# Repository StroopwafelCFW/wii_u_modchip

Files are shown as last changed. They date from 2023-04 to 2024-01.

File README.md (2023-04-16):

# wii_u_modchip

A (WIP) Wii U modchip based on de_Fuse, a flaw in the Wii U's OTP eFuse readout state machine.

## How does it work?
A full writeup is available [here](https://douevenknow.us/post/714056575412764672/defuse-the-one-true-pwn). However, the short version is as follows:

In order to accommodate eFuse-based JTAG lockout (and due to other considerations), eFuse bits must be buffered into a register file immediately following NRST, before the internal reset can be released. The eFuse sense state machine latches at a rate of 4 bits per cycle, directly off the 27MHz XTALCLK. Every other rising edge, a byte is written into the register file, starting from the least significant byte of the current u32.

An internal counter is used to keep track of the remaining bytes to be read into the register file. While the eFuse register file is reset to zero with NRST, the internal counter is not: By asserting NRST after N bytes have been read, only 0x400-N bytes will be read on the subsequent boot.

By asserting NRST just before the final byte has been read (1830 cycles), all eFuses will read entirely zero, including the JTAG lockout fuse. This allows trivial, unsigned and unencrypted boot1 execution, with no SEEPROM anti-rollback.

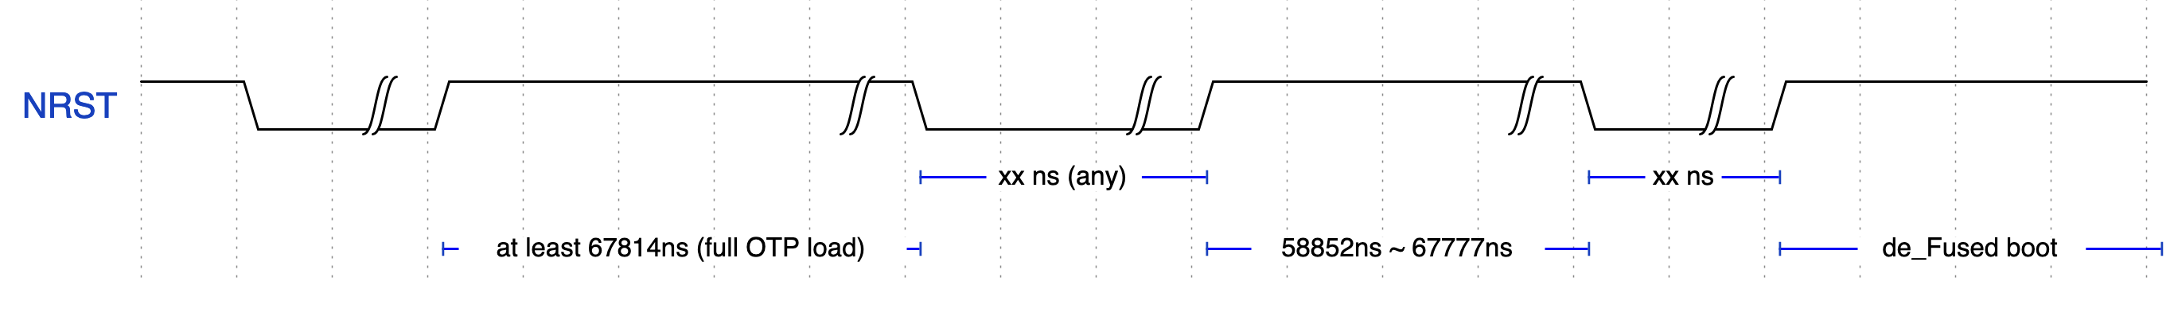
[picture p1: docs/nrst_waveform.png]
NRST waveform


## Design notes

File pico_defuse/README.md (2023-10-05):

# pico de_Fuse

Based on [PicoBoot](https://github.com/webhdx/PicoBoot)

## Wiring

| Pico Pin Name  | Wii U Testpoint | Description |
| --- | --- | --- |
| GP2 | TP50 | DEBUG0 |
| GP3 | TP51 | DEBUG1 |
| GP4 | TP52 | DEBUG2 |
| GP5 | TP53 | DEBUG3 |
| | | |
| GP6 | TP55 | DEBUG4 |
| GP7 | TP54 | DEBUG5 |
| GP8 | TP48 | DEBUG6 |
| GP9 | TP49 | DEBUG7 |
| | | |
| GP10 | TP176 | EXI0 MISO |
| GP11 | TP176 | EXI0 MISO |
| GP12 | TP176 | EXI0 MISO |
| GP13 | TP176 | EXI0 MISO |
| | | |
| GP14 | TP101 | EXI0 CLK |
| GP15 | TP144 (alternatively: R677) | NRST |
| | | |
| GP18 | TP48 | DEBUG6 |
| GP19 | TP48 | DEBUG6 |
| GP20 | TP48 | DEBUG6 |
| GP21 | TP48 | DEBUG6 |
| | | |
| GND |  GND, and/or TP164 | GND |
| 3V3(OUT) |  TP122 | Always-On 3.3v |

wiring diagram
(Thanks to JadeStrike for the wiring diagram)

For wiring to the Pico, I highly suggest using [~38AWG enameled magnet wire](https://www.amazon.com/BNTECHGO-AWG-Magnet-Wire-Transformers/dp/B0823C7C2H) (**not** solid core or stranded). Some of the test points are close to the GPU voltage rails (which are high amperage); A poor solder joint breaking off and touching something else can be catastrophic.

The best location to mount the Pico is still an open question. For my main Wii U, I'm currently planning on placing kapton tape over the Nintendo logo on the top side of the PCB, wrapping my Pico in kapton tape, and then adhering the Pico to the kapton tape with double-sided foam. Wires can be safely routed from the bottom of the PCB to the top through the WiFi antenna divots. I'm also planning on using a [microUSB breakout board](https://www.amazon.com/Adafruit-Micro-B-Breakout-Board-ADA1833/dp/B00KLDPZVU) (wired to the Pico Testpoints) above the HDMI port for serial output.

Apparently some people have managed to [shove entire SSDs](https://gbatemp.net/threads/wii-u-internal-ssd-with-activity-led.606315/) on the underside of the board using electrical tape, so space clearly isn't that big of an issue. But the bigger issue is that the Pico microUSB is currently the only way to perform backups/restores/diagnostics (and the firmware hasn't quite finalized yet), so the USB cable from the Pico has to go ~somewhere out the front of the console or the back.

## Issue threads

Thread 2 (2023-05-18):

Better way of flashing the `pico_defuse` firmware

Supermath101, 2023-05-18:
In the `pico_defuse` README, it says:
> [... But the bigger issue is that the Pico microUSB is currently the only way to perform backups/restores/diagnostics (and the firmware hasn't quite finalized yet), so the USB cable from the Pico has to go ~somewhere out the front of the console or the back.](https://github.com/shinyquagsire23/wii_u_modchip/blob/main/pico_defuse/README.md?plain=1#L39)

I have a suggestion: You can connect a pair of wires (and ground) to the debug pins to load firmware without needing a direct USB connection. You'll want to use the Raspberry Pi Debug Probe (or any standard SWD debugger).

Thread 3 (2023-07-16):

The minute menu does not start v0.7.

Viperbite, 2023-07-16:
1. Recorded boot1 - v0.7 on the card.
2. Copied FW.bin and the WiiU folder.
3. Inserted the card into the console and pressed the power button.
The console turned on, blinked a purple diode and after 20-30 seconds began to blink orange, there is no picture on the screen all this time.

Decision.
1. Write boot1 v0.5.1 to the card.

Question:
1. Is it possible to launch RedNAND at the moment??

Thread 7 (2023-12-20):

Can be done with a esp32 instead a pico?

EnigmaHall, 2023-12-20:
If yes, how?

shinyquagsire23, 2023-12-20:
In theory sure, in practice the Pico's PIO makes everything 10x easier, and making that work on other microcontrollers is left as an exercise for the reader

EnigmaHall, 2023-12-23:
the esp32 is faster and maybe could use the wifi. But my reason is because i dont have a pico. But I understand, remake the work for esp32 take time and effort. Well I will keep my fingers crossed.

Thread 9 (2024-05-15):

[Troubleshooting] Failure to dump OTP.bin with v1.0

VariablePwn, 2024-05-15:
I've tried all day to get OTP.bin to dump with PRSHhax, but unfortunately it would not work at all.
After reading through the GBATemp articles, it seems someone dried using an older version and it worked for them.
I flash v0.8 onto my pico, and overwrote the files on the SD card, and on my second attempt successfully dumped OTP.bin (at least according to the console).

jan-hofmeier, 2024-09-30:
This is fixed in the v1.1 release

Closed 2024-09-30.

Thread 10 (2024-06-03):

You can add a recommended safe GPU overclock range, as the nx venom team?

Armandprogame, 2024-06-03:
Hello Shine, you feel you could add some recommended clock for the wii u gpu so that those who want can overclock it without the risk of breaking it (I know it breaks before but at least I want a overclock safe)

shinyquagsire23, 2024-06-03:
I think something like 800MHz was the theoretical maximum? ie, it crashed the console. But aside from that, it's basically whatever the cooler can safely handle. I honestly don't recommend an overclock *at all* unless you're also doing like, a custom cooler or live in a cold apartment or something.

Armandprogame, 2024-06-03:
Ok thank you then 550mhz and the default while 800mhz is the max but it is only recommended if I have thermal paste or thermal pads aftermarket. Right?

Armandprogame, 2024-06-03:
However, the ihs of the wii u is made of aluminium or and nickel-plated copper? (I know that the heat sink and aluminum so rip contactonaut)

shinyquagsire23, 2024-06-06:
Approximately 750Mhz ± 100MHz, depending on silicon lottery, whether your Wii U is B1X (die shrink), thermal paste and heatsink, probably other factors.

Armandprogame, 2024-06-24:
Shinyquagsire23 I found the safe clock range for the wii u and it's between 550mhz and 600mhz (because it's the maximum frequency of the original wii u video card or amd radeon E6760) and nothing I wanted to know if you could do the test of overclocking the wii u no longer at 680mhz but at 600mhz and see if it overheats anyway. if not then I see and invent a hypothetical overclock that Nintendo would do its own (which is usually and quite undersized)

Armandprogame, 2024-06-24:
I have seen precisely what the native clock of the Wii U amounts to in terms of percentage, or 550mhz and equals a performance efficiency of 91.5/91.6% obviously not and at most of its possibilities that it is 600mhz also considering the fact that the CPU is already at 100% of the maximum working clock already preset by Nintendo instead of which in the video card has been deliberately downclocked by 50mhz, so try this new frequency and let me know if it does not heat more. @
![Screenshot_20240624_134530_Chrome] (https://github.com/shinyquagsire23/wii_u_modchip/assets/115667084/722abba8-540d-4d2a-97df-0657d756046e)

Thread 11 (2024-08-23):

[Question] Wiring additional usb port

dazzaXx, 2024-08-23:
Hello!

I'm planning on adding an extra usb port to the pico via the test pads on it as recommended. Would I need to wire power from the new usb port to the pico? Or is it just the data lines and ground.

Thank You!

dazzaXx, 2024-08-25:
It is just the data lines and ground, also don't wire the usb port to one of the Wii U's. Doesn't work.

Closed 2024-08-24.

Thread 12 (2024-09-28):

Use de_Fuse with RP-2040 Zero

popwow47, 2024-09-28:
Hello! Can you please tell me if I can use the RP-2040 Zero instead of the Raspberry Pi Pico (because I don't have one)?
What was done:
1) I uploaded the pico_defuse.uf2 firmware to the RP-2040 Zero
2) I soldered all the wires according to the installation diagram provided
3) I flashed boot1.img to the SD card, then created a new FAT32 partition to place the remaining files necessary for loading, namely fw.img and the wiiu directory

As soon as I try to start the console, the blue indicator lights up on the front panel and the image does not appear on the monitor. The RP-2040 Zero itself does not indicate anything

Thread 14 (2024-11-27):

How to use the Interactive debug console?

Tz1rf, 2024-11-27:
Is this console functioning? If it is, is there any documentation available on how to use it? Thanks

LevitateGamer, 2024-11-29:
Over HDMI/AV or Usb to pc? Also, I saw both videos on this topic by you and the 1st video (the soldering video) helped me realize the issue with vias around those solder points.

Tz1rf, 2024-11-29:
Are you suggesting that it works over both HDMI/AV and USB to PC? If so I wouldn't mind knowing how to use both if you are willing to share information. That being said to keep thing simple we can just start with one of the methods.

Since you have seen both videos feel free to provide feedback. I put those videos out there so others can learn from them and I don't claim to be, nor am I an expert with Defuse or with repairing Wii U consoles.

I just took an interest in these consoles because I happen to come across a pair of them over a year ago that were marked 160-0103 and upon inquiring about the error the individual who had them told me it was impossible to repair and me being ignorant thought there is no way that can be true, this is a Nintendo console there has to be some way to fix it and down the rabbit hole I went.

I do have another question. The serial console is interactive correct? I am asking because I recall being able to select menu items and move the cursor up and down with the arrow keys on my keyboard. Then sometime around or after installing ISFShax on the console this stopped working. So either I imagined it or it was working and there is a problem with putty or something changed with the console I did this testing on.

What is the issue that you realized with vias around those solder points?

LevitateGamer, 2024-11-29:
#1 Its hard to find a source on how to operate the menu. I know how to operate the menu on the console itself only. I found it here: https://lazr1026.github.io/unbrick/#/ in short you can use the power button to cycle and the eject button to select an option. This link also tells you how to restore a backup as well as other functions. #2 I think the serial console is interactive. I think over serial it uses up and down arrow keys and enter to select. I also think after ISFShax being installed like you described, it will be able to navigated using power and select since it wont work with arrow keys. #3 The issue you said, as far as I, remember was that you have to use Kapton tape to prevent a short to any vias.

LevitateGamer, 2024-11-29:
Btw those # links you can Ignore, its me not realizing it would create a link to issues.

Tz1rf, 2024-11-29:
This isn't what I was looking for. I was specifically referring to the option in the latest version of minute that says "Interactive Debug Console" I wanted to know if this console was operational and how to use it.

LevitateGamer, 2024-11-29:
Sorry for the misunderstanding, are you talking about de_Fuse ZIP v0.5?

Tz1rf, 2024-11-29:
Its the option located in the minute menu.

LevitateGamer, 2024-11-29:
I can't seem to find any documentation on this option. It also might just be the same navigation method as the minute menu.

Tz1rf, 2024-11-29:
I thought that defuse would be required for an interactive debug console to work because it would make use of the serial console. Perhaps I was mistaken in my line of thinking and this post should be under the minute menu github page.

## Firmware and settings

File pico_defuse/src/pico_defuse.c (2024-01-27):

#include <stdio.h>
#include <string.h>
#include "pico/stdlib.h"
#include "hardware/pio.h"
#include "hardware/clocks.h"
#include "hardware/dma.h"
#include "hardware/structs/bus_ctrl.h"
#include "hardware/sync.h" 
#include "pico_defuse.pio.h"

const uint PIN_DEBUGLED_BASE = 2;   // 8 consecutive pins
const uint PIN_SERIALOUT_BASE = 18; // 4 consecutive pins tied together

const uint PIN_LED = 25;                // Status LED
const uint PIN_DATA_BASE = 10;          // Base pin used for output, 4 consecutive pins are used 
const uint PIN_NRST = 15;               // Wii U reset
const uint PIN_CLK = 14;                // EXI bus clock line

uint8_t read_debug_gpios[0x100] = {0};

int nrst_fallback = 0;
PIO pio;
PIO pio_exi;
int debug_gpio_monitor_dmachan;
dma_channel_config debug_gpio_monitor_dmacfg;
uint debug_gpio_monitor_parallel_sm;
uint exi_inject_sm;
uint exi_inject_offset;
uint debug_gpio_monitor_parallel_offset;
uint debug_gpio_monitor_serial_offset;

#define MONITOR_SERIAL_DATA (0)
#define MONITOR_SERIAL_TEXT (1)

#define WIIU_STATE_POWERED_OFF    (0)
#define WIIU_STATE_NEEDS_DEFUSE   (1)
#define WIIU_STATE_DEFUSED        (2)
#define WIIU_STATE_MONITORING     (3)
#define WIIU_CHECK_IF_POWERED_OFF (4)
#define WIIU_STATE_NORMAL_BOOT    (5)

const char* WIIU_STATE_NAMES[6] = {
    "WIIU_STATE_POWERED_OFF",
    "WIIU_STATE_NEEDS_DEFUSE",
    "WIIU_STATE_DEFUSED",
    "WIIU_STATE_MONITORING",
    "WIIU_CHECK_IF_POWERED_OFF",
    "WIIU_STATE_NORMAL_BOOT"
};

const uint32_t serial_LUT[256] = {
    0x00000000,0x0000000f,0x000000f0,0x000000ff,
    0x00000f00,0x00000f0f,0x00000ff0,0x00000fff,
    0x0000f000,0x0000f00f,0x0000f0f0,0x0000f0ff,
    0x0000ff00,0x0000ff0f,0x0000fff0,0x0000ffff,
    0x000f0000,0x000f000f,0x000f00f0,0x000f00ff,
    0x000f0f00,0x000f0f0f,0x000f0ff0,0x000f0fff,
    0x000ff000,0x000ff00f,0x000ff0f0,0x000ff0ff,
    0x000fff00,0x000fff0f,0x000ffff0,0x000fffff,
    0x00f00000,0x00f0000f,0x00f000f0,0x00f000ff,
    0x00f00f00,0x00f00f0f,0x00f00ff0,0x00f00fff,
    0x00f0f000,0x00f0f00f,0x00f0f0f0,0x00f0f0ff,
    0x00f0ff00,0x00f0ff0f,0x00f0fff0,0x00f0ffff,
    0x00ff0000,0x00ff000f,0x00ff00f0,0x00ff00ff,
    0x00ff0f00,0x00ff0f0f,0x00ff0ff0,0x00ff0fff,
    0x00fff000,0x00fff00f,0x00fff0f0,0x00fff0ff,
    0x00ffff00,0x00ffff0f,0x00fffff0,0x00ffffff,
    0x0f000000,0x0f00000f,0x0f0000f0,0x0f0000ff,
    0x0f000f00,0x0f000f0f,0x0f000ff0,0x0f000fff,
    0x0f00f000,0x0f00f00f,0x0f00f0f0,0x0f00f0ff,
    0x0f00ff00,0x0f00ff0f,0x0f00fff0,0x0f00ffff,
    0x0f0f0000,0x0f0f000f,0x0f0f00f0,0x0f0f00ff,
    0x0f0f0f00,0x0f0f0f0f,0x0f0f0ff0,0x0f0f0fff,
    0x0f0ff000,0x0f0ff00f,0x0f0ff0f0,0x0f0ff0ff,
    0x0f0fff00,0x0f0fff0f,0x0f0ffff0,0x0f0fffff,
    0x0ff00000,0x0ff0000f,0x0ff000f0,0x0ff000ff,
    0x0ff00f00,0x0ff00f0f,0x0ff00ff0,0x0ff00fff,
    0x0ff0f000,0x0ff0f00f,0x0ff0f0f0,0x0ff0f0ff,
    0x0ff0ff00,0x0ff0ff0f,0x0ff0fff0,0x0ff0ffff,
    0x0fff0000,0x0fff000f,0x0fff00f0,0x0fff00ff,
    0x0fff0f00,0x0fff0f0f,0x0fff0ff0,0x0fff0fff,
    0x0ffff000,0x0ffff00f,0x0ffff0f0,0x0ffff0ff,
    0x0fffff00,0x0fffff0f,0x0ffffff0,0x0fffffff,
    0xf0000000,0xf000000f,0xf00000f0,0xf00000ff,
    0xf0000f00,0xf0000f0f,0xf0000ff0,0xf0000fff,
    0xf000f000,0xf000f00f,0xf000f0f0,0xf000f0ff,
    0xf000ff00,0xf000ff0f,0xf000fff0,0xf000ffff,
    0xf00f0000,0xf00f000f,0xf00f00f0,0xf00f00ff,
    0xf00f0f00,0xf00f0f0f,0xf00f0ff0,0xf00f0fff,
    0xf00ff000,0xf00ff00f,0xf00ff0f0,0xf00ff0ff,
    0xf00fff00,0xf00fff0f,0xf00ffff0,0xf00fffff,
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
};

const uint8_t MONITOR_SERIAL_DATA_MAGIC[12] = {0x55, 0xAA, 0x55, 0xAA, 0x55, 0xAA, 0x55, 0xAA, 0xBE, 0xEF, 0xCA, 0xFE};
const uint8_t MONITOR_SERIAL_TEXT_MAGIC[12] = {0x55, 0xAA, 0x55, 0xAA, 0x55, 0xAA, 0x55, 0xAA, 0xF0, 0x0F, 0xCA, 0xFE};
const uint8_t MONITOR_PARALLEL_DATA_MAGIC[12] = {0x55, 0xAA, 0x55, 0xAA, 0x55, 0xAA, 0x55, 0xAA, 0xBE, 0xEF, 0xBE, 0xEF};
const uint8_t MONITOR_RESET_MAGIC[12] = {0x55, 0xAA, 0x55, 0xAA, 0x55, 0xAA, 0x55, 0xAA, 0x4E, 0x52, 0x53, 0x54};
const uint8_t MONITOR_RESET_PRSHHAX_MAGIC[12] = {0x55, 0xAA, 0x55, 0xAA, 0x55, 0xAA, 0x55, 0xAA, 0x50, 0x52, 0x53, 0x48};

char text_buffer[2048];
int text_buffer_pos = 0;
uint8_t last_16_bytes[16] = {0};
uint8_t serial_data_cnt = 0;
uint8_t current_mode = MONITOR_SERIAL_DATA;
uint8_t num_serial_loops = 0;

uint8_t wiiu_state = WIIU_STATE_POWERED_OFF;
uint8_t next_wiiu_state = WIIU_STATE_POWERED_OFF;
bool nrst_sense_state = false;

// Cycle-accurate JTAG enable
//#define DEFUSE_JTAG
#define DEFUSE_BYTE_UNIT (0x4)

#ifdef DEFUSE_JTAG
// Start from 0 and increase this to make it boot slightly faster,
// instead of just overshooting it for the guarantee
#define JTAG_VARIANCE (1)

#define RESET_RANGE_MIN (RESET_RANGE_MAX-(DEFUSE_BYTE_UNIT/2))
#define RESET_RANGE_MAX (0xEA8-JTAG_VARIANCE)
#else
#define RESET_RANGE_MIN (RESET_RANGE_MAX-(DEFUSE_BYTE_UNIT*0x40))
#define RESET_RANGE_MAX (0xE8C-(DEFUSE_BYTE_UNIT*0x7D))
#endif

// Empty OTP w/ JTAG disabled
//#define RESET_RANGE_MIN (RESET_RANGE_MAX-(DEFUSE_BYTE_UNIT*0x40))
//#define RESET_RANGE_MAX (0xE8C-(DEFUSE_BYTE_UNIT*0))

void nrst_sense_callback(uint gpio, uint32_t events) 
{
    //printf("NRST %x\n", events);

    // NRST went from low to high, we need to inject de_Fuse
    if (events & 8)
    {
        switch (wiiu_state)
        {
        case WIIU_STATE_POWERED_OFF:
        case WIIU_CHECK_IF_POWERED_OFF:
            next_wiiu_state = WIIU_STATE_NEEDS_DEFUSE;
            break;
        }
    }
    else if (events & 4) {
        next_wiiu_state = WIIU_CHECK_IF_POWERED_OFF;
    }
    
}

void nrst_sense_set(bool is_on)
{
    gpio_set_function(PIN_NRST, GPIO_FUNC_SIO);

    if (is_on == nrst_sense_state) {
        return;
    }

    if (is_on) {
        gpio_put(PIN_NRST, true);
        gpio_set_dir(PIN_NRST, GPIO_IN);
        gpio_set_irq_enabled_with_callback(PIN_NRST, GPIO_IRQ_EDGE_RISE | GPIO_IRQ_EDGE_FALL, true, &nrst_sense_callback);
    }
    else {
        gpio_set_irq_enabled_with_callback(PIN_NRST, GPIO_IRQ_EDGE_RISE | GPIO_IRQ_EDGE_FALL, false, &nrst_sense_callback);
        gpio_put(PIN_NRST, true);
        gpio_set_dir(PIN_NRST, GPIO_OUT);
    }
    nrst_sense_state = is_on;
}

// Stuff that needs to happen extremely early
void fast_one_time_init()
{
    stdio_init_all();

    // LED on for now to indicate life or something
    gpio_init(PIN_LED);
    gpio_set_dir(PIN_LED, GPIO_OUT);
    gpio_put(PIN_LED, true);

    gpio_init(PIN_NRST);
    gpio_set_dir(PIN_NRST, GPIO_IN);
    gpio_put(PIN_NRST, true); // make sure we don't accidentally inject rst pulses when switching dirs lol

    // TODO: figure out the bare minimum I can pull off (maybe downclock later?)
    // 250MHz seems to capture debug pin transistions, which was the ~status quo
    // on my FPGA at 27MHz. Let's do 4x27MHz to be safe.
    set_sys_clock_khz(108000, true);

    wiiu_state = WIIU_STATE_POWERED_OFF;
    next_wiiu_state = WIIU_STATE_POWERED_OFF;
    nrst_sense_set(true);
}

void slow_one_time_init()
{
    // Prioritize DMA engine
    bus_ctrl_hw->priority = BUSCTRL_BUS_PRIORITY_DMA_W_BITS | BUSCTRL_BUS_PRIORITY_DMA_R_BITS;

    // From PicoBoot: put some extra oomph into the EXI data pin,
    // because the Wii U has a stupidly high current sink on inputs
    gpio_set_slew_rate(PIN_DATA_BASE, GPIO_SLEW_RATE_FAST);
    gpio_set_slew_rate(PIN_DATA_BASE + 1, GPIO_SLEW_RATE_FAST);
    gpio_set_slew_rate(PIN_DATA_BASE + 2, GPIO_SLEW_RATE_FAST);
    gpio_set_slew_rate(PIN_DATA_BASE + 3, GPIO_SLEW_RATE_FAST);

    gpio_set_drive_strength(PIN_DATA_BASE, GPIO_DRIVE_STRENGTH_4MA);
    gpio_set_drive_strength(PIN_DATA_BASE + 1, GPIO_DRIVE_STRENGTH_4MA);
    gpio_set_drive_strength(PIN_DATA_BASE + 2, GPIO_DRIVE_STRENGTH_4MA);
    gpio_set_drive_strength(PIN_DATA_BASE + 3, GPIO_DRIVE_STRENGTH_4MA);

    pio = pio0;
    pio_exi = pio1;

    // We use two statemachines: one for the debug monitor, and one for the EXI injecting.
    debug_gpio_monitor_parallel_sm = pio_claim_unused_sm(pio, true);
    exi_inject_sm = pio_claim_unused_sm(pio_exi, true);

    // The exi inject statemachine is only used during de_Fusing, it just watches
    // for 64 EXI clks and shoves the line high so the SDboot bit gets read as 1.
    exi_inject_offset = pio_add_program(pio_exi, &exi_inject_program);

    // The debug monitor has two programs: The parallel monitor, used to check boot0
    // codes, and the serial monitor, which is used for the text console in minute/etc
    debug_gpio_monitor_parallel_offset = pio_add_program(pio, &debug_gpio_monitor_parallel_program);
    debug_gpio_monitor_serial_offset = pio_add_program(pio, &debug_gpio_monitor_serial_program);
    
    // Debug monitor can start early, it's basically always on.
    debug_gpio_monitor_parallel_program_init(pio, debug_gpio_monitor_parallel_sm, debug_gpio_monitor_parallel_offset, PIN_DEBUGLED_BASE, PIN_SERIALOUT_BASE, 1.0);
    pio_sm_set_enabled(pio, debug_gpio_monitor_parallel_sm, true);

    // Set up DMA for reading results, but don't start it yet.
    debug_gpio_monitor_dmachan = dma_claim_unused_channel(true);
    debug_gpio_monitor_dmacfg = dma_channel_get_default_config(debug_gpio_monitor_dmachan);
    channel_config_set_transfer_data_size(&debug_gpio_monitor_dmacfg, DMA_SIZE_8);
    channel_config_set_read_increment(&debug_gpio_monitor_dmacfg, false);
    channel_config_set_write_increment(&debug_gpio_monitor_dmacfg, true);
    channel_config_set_dreq(&debug_gpio_monitor_dmacfg, pio_get_dreq(pio, debug_gpio_monitor_parallel_sm, false));
}

void do_normal_reset()
{
    // Disable NRST sensing and take control of the line.
    nrst_sense_set(false);

    // Read OTP fully at least once and then hold.
    // We do this twice just in case.
    // This boot does not need EXI injection, because
    // we try to make sure it ends before it hits boot1.
    gpio_put(PIN_NRST, false);
    for(int i = 0; i < 0x100; i++)
    {
        __asm volatile ("\n");
    }
    gpio_put(PIN_NRST, true);
    for(int i = 0; i < 0x4000; i++) // boot0 is running for 0x4000 ticks
    {
        __asm volatile ("\n");
    }
    gpio_put(PIN_NRST, false);
    for(int i = 0; i < 0x100; i++)
    {
        __asm volatile ("\n");
    }
    gpio_put(PIN_NRST, true);
    for(int i = 0; i < 0x4000; i++) // boot0 is running for 0x4000 ticks
    {
        __asm volatile ("\n");
    }
    gpio_put(PIN_NRST, false);
    for(int i = 0; i < 0x100; i++)
    {
        __asm volatile ("\n");
    }

    // Hopefully any de_Fuse quirks are flushed out, do the real reset
    gpio_put(PIN_NRST, false);
    for(int i = 0; i < 0x100; i++)
    {
        __asm volatile ("\n");
    }
    gpio_put(PIN_NRST, true);
    for(int i = 0; i < 0x4000; i++)
    {
        __asm volatile ("\n");
    }
    next_wiiu_state = WIIU_STATE_NORMAL_BOOT;
}

void de_fuse()
{
    // Disable NRST sensing and take control of the line.
    nrst_sense_set(false);

    // Make sure parallel debug monitor is on
    debug_gpio_monitor_parallel_program_init(pio, debug_gpio_monitor_parallel_sm, debug_gpio_monitor_parallel_offset, PIN_DEBUGLED_BASE, PIN_SERIALOUT_BASE, 1.0);
    pio_sm_set_enabled(pio, debug_gpio_monitor_parallel_sm, true);

    // winning range (at 8x27MHz): 0xB40 ~ 0x703 -- long tail? 0xbb9 ~ 0x461 (optimal: 0x900, 0x48 bytes OTP loaded)
    // winning range (at 4x27MHz): 0x5a0 ~ 0x381 -- (optimal: 0x480, 0x48 bytes OTP loaded)
    int winner = 0;
    uint8_t error_code = 0;
    int only_zeros = 1;
    for (int reset_attempt = RESET_RANGE_MAX; reset_attempt >= RESET_RANGE_MIN; reset_attempt--)
    {
        for (int which = 0; which < 2; which++)
        {
            only_zeros = 1;
            winner = 0;
            error_code = 0;

            // Make sure the last attempt does not give a false success
            if (reset_attempt == RESET_RANGE_MIN && which) {
                break;
            }

            printf("Starting... %u:%u\n", reset_attempt, which);
            pio_sm_set_enabled(pio, debug_gpio_monitor_parallel_sm, true);
            exi_inject_program_init(pio_exi, exi_inject_sm, exi_inject_offset, PIN_CLK, PIN_DATA_BASE, 1.0);

            // Read OTP fully at least once and then hold.
            // We do this twice just in case.
            // This boot does not need EXI injection, because
            // we try to make sure it ends before it hits boot1.
            gpio_put(PIN_NRST, false);
            for(int i = 0; i < 0x100; i++)
            {
                __asm volatile ("\n");
            }
            gpio_put(PIN_NRST, true);
            for(int i = 0; i < 0x4000; i++)
            {
                __asm volatile ("\n");
            }
            gpio_put(PIN_NRST, false);
            for(int i = 0; i < 0x100; i++)
            {
                __asm volatile ("\n");
            }
            gpio_put(PIN_NRST, true);
            for(int i = 0; i < 0x4000; i++)
            {
                __asm volatile ("\n");
            }
            gpio_put(PIN_NRST, false);
            for(int i = 0; i < 0x100; i++)
            {
                __asm volatile ("\n");
            }

    #if 1
            // The actual timing-sensitive part...
            // This won't even reach boot1, it just has to get the fuse
            // readout counter to a value >0x380 so that the next
            // boot is de_Fused.
            uint32_t cookie = save_and_disable_interrupts();
            gpio_put(PIN_NRST, true);

            for(int i = 0; i < reset_attempt; i++)
            {
                __asm volatile ("\n");
            }

            // OK, we're done
            gpio_put(PIN_NRST, false);
            restore_interrupts(cookie);
    #endif

            // Clear out the FIFO so our results readout is clean.
            for (int i = 0; i < 0x20; i++)
            {
                pio_sm_get(pio, debug_gpio_monitor_parallel_sm);
            }

            // Start DMAing results while we're held in reset
            memset(read_debug_gpios, 0, sizeof(read_debug_gpios));
            dma_channel_configure(
                debug_gpio_monitor_dmachan,
                &debug_gpio_monitor_dmacfg,
                read_debug_gpios,
                &pio->rxf[debug_gpio_monitor_parallel_sm],
                sizeof(read_debug_gpios),
                true // start immediately
            );

            // Make extra sure we've held in reset long enough
            // for the not-eFuse things on the chip that actually 
            // reset correctly lol
            for(int i = 0; i < 0x100; i++)
            {
                __asm volatile ("\n");
            }

            // Start EXI injection and deassert reset
            pio_sm_set_enabled(pio_exi, exi_inject_sm, which ? false : true);
            gpio_put(PIN_NRST, true);

            // Give it enough time to reach boot1, then
            // disable all the debug monitor and EXI injector so we
            // can check the results
            if (reset_attempt <= RESET_RANGE_MIN+4) {
                sleep_ms(500);
            }
            sleep_ms(200);
            dma_channel_abort(debug_gpio_monitor_dmachan);
            pio_sm_set_enabled(pio, debug_gpio_monitor_parallel_sm, false);
            pio_sm_set_enabled(pio_exi, exi_inject_sm, false);

            // Winner?
            printf("Results:\n");
            for (int i = 0; i < 0x100; i++)
            {
                if (read_debug_gpios[i]) {
                    only_zeros = 0;
                }
                if (i && read_debug_gpios[i] == read_debug_gpios[i-1]) {
                    break;
                }
                if (read_debug_gpios[i] == 0x88) { // || read_debug_gpios[i] == 0x25
                    winner = 1;
                }
                if (read_debug_gpios[i] == 0xE1) {
                    winner = 0;
                }

                if (read_debug_gpios[i] >= 0xC0) {
                    error_code = read_debug_gpios[i];
                }
            }

            if (winner) {
                printf("Winner! 0x%x\n", 0x10000 - reset_attempt);
                
                for (int i = 0; i < 0x100; i++)
                {
                    printf("%02x\n", read_debug_gpios[i]);
                    if (i && read_debug_gpios[i] == read_debug_gpios[i-1]) {
                        break;
                    }
                }
                next_wiiu_state = WIIU_STATE_DEFUSED;
                goto glitch_success;
            }
            else {
                for (int i = 0; i < 0x100; i++)
                {
                    printf("%02x\n", read_debug_gpios[i]);
                    if (i && read_debug_gpios[i] == read_debug_gpios[i-1]) {
                        break;
                    }
                }
                printf("Error code: %02x\n", error_code);
            }
        }
        //sleep_ms(1000);
    }

glitch_success:

    // JTAG has a much smaller window
#ifndef DEFUSE_JTAG
    // TODO: do this after trying a NAND boot1?
    // If no SD card is inserted, or an invalid one is inserted, boot0 stalls.
    if (!winner && error_code == 0x00 && !only_zeros) {
        printf("SD card not valid or not inserted, doing a normal boot.\n");
        do_normal_reset();
    }

    if (!winner && only_zeros) {
        printf("[Pico] Wii U doesn't seem to be powered on?\n");
        next_wiiu_state = WIIU_CHECK_IF_POWERED_OFF;
    }
#else
    ;
#endif
}

void post_de_fuse()
{
    // Switch to serial monitor and monitor NRST
    debug_gpio_monitor_serial_program_init(pio, debug_gpio_monitor_parallel_sm, debug_gpio_monitor_serial_offset, PIN_DEBUGLED_BASE, PIN_SERIALOUT_BASE, 1.0);
    nrst_sense_set(true);
    memset(text_buffer, 0, sizeof(text_buffer));
    text_buffer_pos = 0;

    pio_sm_set_enabled(pio, debug_gpio_monitor_parallel_sm, true);
    memset(last_16_bytes, 0, sizeof(last_16_bytes));
    serial_data_cnt = 0;
    current_mode = MONITOR_SERIAL_TEXT;

    next_wiiu_state = WIIU_STATE_MONITORING;
}
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
void main()
{
    fast_one_time_init();

    // Keep this delay so that if the MCU hangs for whatever reason, the user
    // can unplug the console and race to flash it w/o needing the program btn
    sleep_ms(3000);
    printf("hello there\n");

    slow_one_time_init();

    printf("Start state machine.\n");
#if 0
    if (gpio_get(PIN_NRST)) {
        printf("[pico] Uhhh the console is on? Monitoring...\n");
        wiiu_state = WIIU_STATE_DEFUSED;
        next_wiiu_state = WIIU_STATE_DEFUSED;
    }
#endif
    if (gpio_get(PIN_NRST)) {
        printf("[pico] Uhhh the console is on? Defusing now...?\n");
        wiiu_state = WIIU_STATE_NEEDS_DEFUSE;
        next_wiiu_state = WIIU_STATE_NEEDS_DEFUSE;
    }

    // State machines yayyyy
    while (1)
    {
        switch (wiiu_state)
        {
        case WIIU_STATE_NORMAL_BOOT:
            nrst_sense_set(true); // wait for IRQs
            fallback_power_check();
            break;

        case WIIU_STATE_POWERED_OFF:
            nrst_sense_set(true); // wait for IRQs
            break;

        // Kinda redundant since the IRQ should catch the rising edge, 
        // but juuuust to be sure.
        case WIIU_CHECK_IF_POWERED_OFF:
            nrst_sense_set(true);
            sleep_ms(10);
            if (gpio_get(PIN_NRST)) {
                next_wiiu_state = WIIU_STATE_NEEDS_DEFUSE;
            }
            else {
                next_wiiu_state = WIIU_STATE_POWERED_OFF;
            }
            break;

        case WIIU_STATE_NEEDS_DEFUSE:
            de_fuse();
            //next_wiiu_state = WIIU_STATE_DEFUSED;
            break;

        case WIIU_STATE_DEFUSED:
            post_de_fuse();
            break;

        case WIIU_STATE_MONITORING:
            wiiu_serial_monitor();
            fallback_power_check();
            break;
        }

        

        if (wiiu_state != next_wiiu_state)
            printf("[pico] Changed state: %s -> %s\n", WIIU_STATE_NAMES[wiiu_state], WIIU_STATE_NAMES[next_wiiu_state]);
        wiiu_state = next_wiiu_state;
    }
}

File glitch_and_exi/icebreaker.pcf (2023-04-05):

# 12 MHz clock
set_io -nowarn CLK        35
set_frequency CLK 27

# RS232
set_io -nowarn RX          6
set_io -nowarn TX          9

# LEDs and Button
set_io -nowarn BTN_N      10
set_io -nowarn LEDR_N     11
set_io -nowarn LEDG_N     37

# RGB LED Driver
set_io -nowarn LED_RED_N  39
set_io -nowarn LED_GRN_N  40
set_io -nowarn LED_BLU_N  41
set_io -nowarn LED_RGB[0] 39
set_io -nowarn LED_RGB[1] 40
set_io -nowarn LED_RGB[2] 41

# SPI Flash
set_io -nowarn FLASH_SCK  15
set_io -nowarn FLASH_SSB  16
set_io -nowarn FLASH_IO0  14
set_io -nowarn FLASH_IO1  17
set_io -nowarn FLASH_IO2  12
set_io -nowarn FLASH_IO3  13

# PMOD 1A
set_io -nowarn P1A1        4
set_io -nowarn P1A2        2
set_io -nowarn P1A3       47
set_io -nowarn P1A4       45
set_io -nowarn P1A7        3
set_io -nowarn P1A8       48
set_io -nowarn P1A9       46
set_io -nowarn P1A10      44

# PMOD 1B
set_io -nowarn P1B1       43
set_io -nowarn P1B2       38
set_io -nowarn P1B3       34
set_io -nowarn P1B4       31
set_io -nowarn P1B7       42
set_io -nowarn P1B8       36
set_io -nowarn P1B9       32
set_io -nowarn P1B10      28

# PMOD 2
set_io -nowarn P2_1       27
set_io -nowarn P2_2       25
set_io -nowarn P2_3       21
set_io -nowarn P2_4       19
set_io -nowarn P2_7       26
set_io -nowarn P2_8       23
set_io -nowarn P2_9       20
set_io -nowarn P2_10      18

# LEDs and Buttons (PMOD 2)
set_io -nowarn LED1       26
set_io -nowarn LED2       27
set_io -nowarn LED3       25
set_io -nowarn LED4       23
set_io -nowarn LED5       21
set_io -nowarn BTN1       20
set_io -nowarn BTN2       19
set_io -nowarn BTN3       18

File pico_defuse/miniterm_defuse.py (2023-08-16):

#!/usr/bin/env python
#
# Very simple serial terminal
#
# This file is part of pySerial. https://github.com/pyserial/pyserial
# (C)2002-2020 Chris Liechti <cliechti@gmx.net>
#
# SPDX-License-Identifier:    BSD-3-Clause

from __future__ import absolute_import

import codecs
import os
import sys
import threading

import struct
import serial
from serial.tools.list_ports import comports
from serial.tools import hexlify_codec

# pylint: disable=wrong-import-order,wrong-import-position

codecs.register(lambda c: hexlify_codec.getregentry() if c == 'hexlify' else None)

MAGIC_UPLD = [0x55, 0xaa, 0x55, 0xaa, 0x55, 0xaa, 0x55, 0xaa, 0x55, 0x50, 0x4C, 0x44]

try:
    raw_input
except NameError:
    # pylint: disable=redefined-builtin,invalid-name
    raw_input = input   # in python3 it's "raw"
    unichr = chr


def key_description(character):
    """generate a readable description for a key"""
    ascii_code = ord(character)
    if ascii_code < 32:
        return 'Ctrl+{:c}'.format(ord('@') + ascii_code)
    else:
        return repr(character)


# - - - - - - - - - - - - - - - - - - - - - - - - - - - - - - - - - - - - - -
class ConsoleBase(object):
    """OS abstraction for console (input/output codec, no echo)"""

    def __init__(self, miniterm):
        self.miniterm = miniterm
        if sys.version_info >= (3, 0):
            self.byte_output = sys.stdout.buffer
        else:
            self.byte_output = sys.stdout
        self.output = sys.stdout

    def setup(self):
        """Set console to read single characters, no echo"""

    def cleanup(self):
        """Restore default console settings"""

    def getkey(self):
        """Read a single key from the console"""
        return None

    def write_bytes(self, byte_string):
        """Write bytes (already encoded)"""
        self.byte_output.write(byte_string)
        self.byte_output.flush()

    def write(self, text):
        """Write string"""
        self.output.write(text)
        self.output.flush()

    def cancel(self):
        """Cancel getkey operation"""

    #  -  -  -  -  -  -  -  -  -  -  -  -  -  -  -  -  -  -  -  -  -  -  -  -
    # context manager:
    # switch terminal temporary to normal mode (e.g. to get user input)

    def __enter__(self):
        self.cleanup()
        return self

    def __exit__(self, *args, **kwargs):
        self.setup()


if os.name == 'nt':  # noqa
    import msvcrt
    import ctypes
    import platform

    class Out(object):
        """file-like wrapper that uses os.write"""

        def __init__(self, fd):
            self.fd = fd

        def flush(self):
            pass

        def write(self, s):
            os.write(self.fd, s)

    class Console(ConsoleBase):
        fncodes = {
            ';': '\x1bOP',  # F1
            '<': '\x1bOQ',  # F2
            '=': '\x1bOR',  # F3
            '>': '\x1bOS',  # F4
            '?': '\x1b[15~',  # F5
            '@': '\x1b[17~',  # F6
            'A': '\x1b[18~',  # F7
            'B': '\x1b[19~',  # F8
            'C': '\x1b[20~',  # F9
            'D': '\x1b[21~',  # F10
        }
        navcodes = {
            'H': '\x1b[A',  # UP
            'P': '\x1b[B',  # DOWN
            'K': '\x1b[D',  # LEFT
            'M': '\x1b[C',  # RIGHT
            'G': '\x1b[H',  # HOME
            'O': '\x1b[F',  # END
            'R': '\x1b[2~',  # INSERT
            'S': '\x1b[3~',  # DELETE
            'I': '\x1b[5~',  # PAGE UP
            'Q': '\x1b[6~',  # PAGE DOWN
        }

        def __init__(self, miniterm):
            super(Console, self).__init__(miniterm)
            self._saved_ocp = ctypes.windll.kernel32.GetConsoleOutputCP()
            self._saved_icp = ctypes.windll.kernel32.GetConsoleCP()
            ctypes.windll.kernel32.SetConsoleOutputCP(65001)
            ctypes.windll.kernel32.SetConsoleCP(65001)
            # ANSI handling available through SetConsoleMode since Windows 10 v1511 
            # https://en.wikipedia.org/wiki/ANSI_escape_code#cite_note-win10th2-1
            if platform.release() == '10' and int(platform.version().split('.')[2]) > 10586:
                ENABLE_VIRTUAL_TERMINAL_PROCESSING = 0x0004
                import ctypes.wintypes as wintypes
                if not hasattr(wintypes, 'LPDWORD'):  # PY2
                    wintypes.LPDWORD = ctypes.POINTER(wintypes.DWORD)
                SetConsoleMode = ctypes.windll.kernel32.SetConsoleMode
                GetConsoleMode = ctypes.windll.kernel32.GetConsoleMode
                GetStdHandle = ctypes.windll.kernel32.GetStdHandle
                mode = wintypes.DWORD()
                GetConsoleMode(GetStdHandle(-11), ctypes.byref(mode))
                if (mode.value & ENABLE_VIRTUAL_TERMINAL_PROCESSING) == 0:
                    SetConsoleMode(GetStdHandle(-11), mode.value | ENABLE_VIRTUAL_TERMINAL_PROCESSING)
                    self._saved_cm = mode
            self.output = codecs.getwriter('UTF-8')(Out(sys.stdout.fileno()), 'replace')
            # the change of the code page is not propagated to Python, manually fix it
            sys.stderr = codecs.getwriter('UTF-8')(Out(sys.stderr.fileno()), 'replace')
            sys.stdout = self.output
            self.output.encoding = 'UTF-8'  # needed for input

        def __del__(self):
            ctypes.windll.kernel32.SetConsoleOutputCP(self._saved_ocp)
            ctypes.windll.kernel32.SetConsoleCP(self._saved_icp)
            try:
                ctypes.windll.kernel32.SetConsoleMode(ctypes.windll.kernel32.GetStdHandle(-11), self._saved_cm)
            except AttributeError:  # in case no _saved_cm
                pass

        def getkey(self):
            while True:
                z = msvcrt.getwch()
                if z == unichr(13):
                    return unichr(10)
                elif z is unichr(0) or z is unichr(0xe0):
                    try:
                        code = msvcrt.getwch()
                        if z is unichr(0):
                            return self.fncodes[code]
                        else:
                            return self.navcodes[code]
                    except KeyError:
                        pass
                else:
                    return z

        def cancel(self):
            # CancelIo, CancelSynchronousIo do not seem to work when using
            # getwch, so instead, send a key to the window with the console
            hwnd = ctypes.windll.kernel32.GetConsoleWindow()
            ctypes.windll.user32.PostMessageA(hwnd, 0x100, 0x0d, 0)
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

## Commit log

2023-04-07 Serial, and insert reset at the JTAG fuse load instead of ~0x40 bytes in
    [glitch_and_exi.v, monitor.py]
2023-04-16 Attempted to add uart rx input (Wii U drive strength is too high), watch for NRSTs and intercept them
    [glitch_and_exi.v, monitor.py]
2023-04-20 WIP pico firmware: it can read the DEBUG pins via PIO
2023-04-20 pico gets code exec now
2023-04-21 oops: wiring for real
2023-04-21 pico: NRST monitoring state machine
2023-04-21 Fix EXI clobbering minute_minute's reads and cleanup
    [pico_defuse.c]
2023-04-23 More power checks
2023-04-23 oops, found the right voltage line
2023-04-23 Additional notes on wiring
2023-04-27 Byte-accurate OTP defusing on Pico
2023-08-10 add wiring diagram
2023-08-10 Show wiring diagram in README.md
2023-10-23 Pico flatflex CAD files
    [pico_flatflex-B_Cu.gbr, pico_flatflex-B_Mask.gbr, pico_flatflex-B_Paste.gbr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]
2024-01-27 Fix RTC reading 00s on SLC booting sometimes
    [pico_defuse.c]
